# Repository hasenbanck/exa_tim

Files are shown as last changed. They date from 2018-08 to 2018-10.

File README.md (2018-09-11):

# EXA_tim

EXA_tim is a wristwatch that uses GNSS for time synchronization.

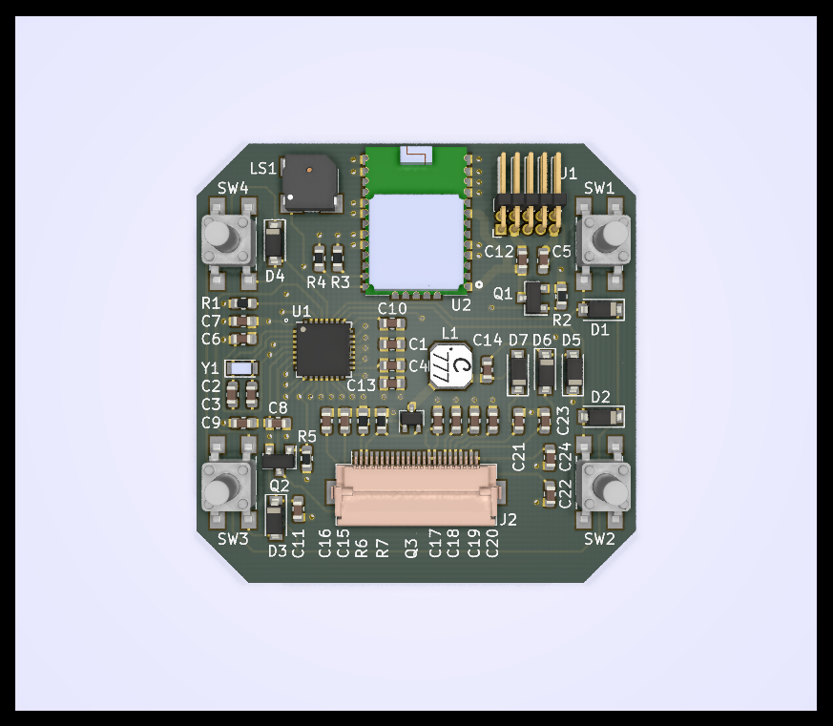
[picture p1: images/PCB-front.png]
EXA_tim PCB front

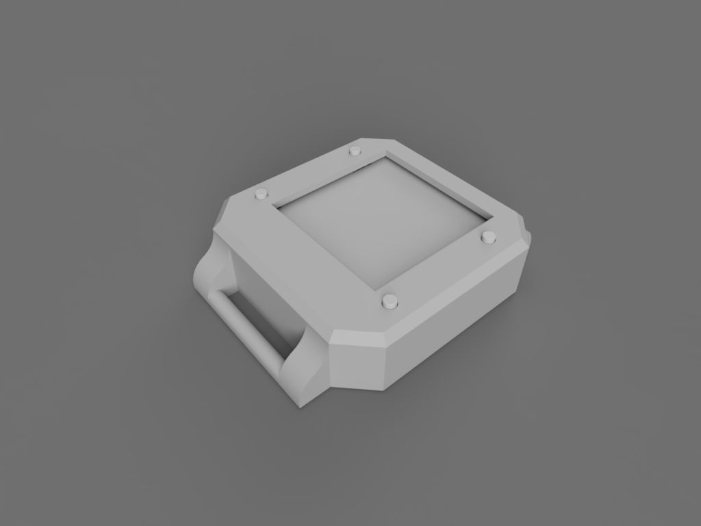
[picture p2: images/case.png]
EXA_tim case


# Features

- 32bit STM32L0 MCU
- GNSS time synchronization (UTC)
- 1.54 inch e-paper display
- 4 buttons
- CR2032 battery

Currently we are aiming for 2-3 months of operation with one battery.

# Case

The case is designed in Fusion 360 and can be viewed here:
https://a360.co/2LLzCpt

A current snapshot is included in the source repository.

The case is designed to be 3D printable and uses a NATO strap.

If you want to 3D print them, you need to either use Fusion 360 or
FreeCAD to export the three components as STL files.

I printed them in PLA and PETG with good results. Low warp material
hightly recommended, since dimensional accuracy is key.

I designed the parts for a printer that can handle 0.1 mm clearance.
If you need looser clearance, please change the Fusion 360 user
variable "Clearance" for your needed value.

# Firmware

The firmware uses the STM32 HAL. It can be build by either using cmake
with the ARM GCC toolchain or by using Atollic TrueStudio.

For the CMAKE build, you need to provide the ARM GCC toolchain in the
PATH of your system. You can choose any CMAKE target that you like
to use. I personaly use ninja.

```bash
cd firmware
cmake -DCMAKE_TOOLCHAIN_FILE=arm-gcc-toolchain.cmake -G Ninja .
ninja
```

You can change add a ```-DCMAKE_BUILD_TYPE=Debug``` to the CMAKE
command to produce a debug build.

# Flashing

To programm the watch we are using the 10 pin 1.27mm (0.05") Cortex Debug
header. You need a programmer that can programm an ARM using the SWD
protocol.

A ST-Link V2 (and it's clones), a JLink (mini) or a blackmagic programmer
should work fine.

We included a OpenOCD file as an example how to programm the firmware.

You can also use any available flashing software available. For example:
 - OpenOCD
 - STM32CubeProgrammer
 - STM32 ST-Link utility
 - Segger J-Link JFlash (lite)

# License

The hardware components (case and PCB) are licensed under the CERN Open
Hardware Licence v1.2

The software components (firmware) are licensed under GPLv3.

The pcb/packages3d files are excluded from these license.

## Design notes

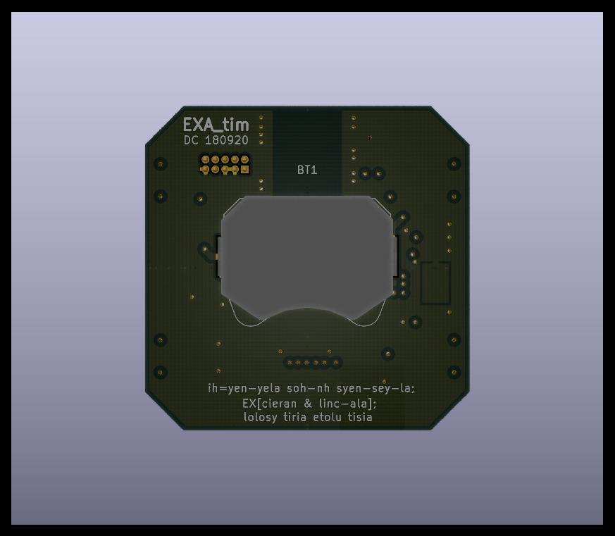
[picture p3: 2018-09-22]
images/PCB-back.png

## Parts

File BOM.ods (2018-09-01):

Item | Reference(s) | Value | Mouser | Qty | Notice | Footprint | Datasheet
1 | BT1 | 3034TR | 534-3034TR | 1 |  | exa_tim:BatteryHolder_Keystone_3034_1x20mm | http://www.keyelco.com/product-pdf.cfm?p=798
2 | C1, C6, C12, C13 | 4.7uF | 963-JMK107C6475MA-T | 4 | 6V | Capacitor_SMD:C_0603_1608Metric | ~
3 | C2, C3 | 20pF | 603-CC0603JR7BN200 | 2 | 6V | Capacitor_SMD:C_0603_1608Metric | ~
4 | C4, C5, C7, C9, C10, C11, C14, C17 | 100nF | 810-C1608X8R1H104M0B | 8 | 50V | Capacitor_SMD:C_0603_1608Metric | ~
5 | C8, C15, C16, C18, C19, C20, C21, C22, C23, C24 | 1uF | 710-885012106022 | 10 | 25V | Capacitor_SMD:C_0603_1608Metric | ~
7 | D1, D2, D3, D4, D5, D6, D7 | MBR0530 | 512-MBR0530 | 7 | Alternative: S310FA | Diode_SMD:D_SOD-123 | https://www.fairchildsemi.com/datasheets/MB/MBR0530.pdf
8 | J1 | 20021112-00010T4LF | 649-200211120001T4LF | 1 |  | Connector_PinHeader_1.27mm:PinHeader_2x05_P1.27mm_Horizontal | http://infocenter.arm.com/help/topic/com.arm.doc.faqs/attached/13634/cortex_debug_connectors.pdf
9 | J2 | FH12-24S-0.5SH(55) | 798-FH12-24S-0.5SH55 | 1 |  | exa_tim:Hirose_FH12-24S-0.5SH_1x24-1MP_P0.50mm_Horizontal | https://www.mouser.de/datasheet/2/185/FH12_catalog-939276.pdf
10 | L1 | LPS4018-683MRB | 994-LPS4018-683MRB | 1 |  | exa_tim:L_Coilcraft_LPS4018 | https://www.mouser.de/datasheet/2/597/lps4018-270702.pdf
11 | LS1 | CSS-0575A-SMT | 490-CSS-0575A-SMT-TR | 1 |  | exa_tim:CUI_CSS-0575A-SMT | ~
12 | Q1 | SI2333DS-T1-E3 | 781-SI2333DS-T1-E3 | 1 |  | Package_TO_SOT_SMD:SOT-23 | https://www.vishay.com/docs/72023/72023.pdf
13 | Q2 | DMN3067LW-7 | 621-DMN3067LW7 | 1 |  | Package_TO_SOT_SMD:SOT-323_SC-70 | https://www.mouser.de/datasheet/2/115/DMN3067LW-335715.pdf
14 | R1, R3, R6 | 1M | 603-RC0603JR-131ML | 3 |  | Resistor_SMD:R_0603_1608Metric | ~
16 | R2, R4, R5 | 220 | 603-RC0603JR-13220RL | 3 |  | Resistor_SMD:R_0603_1608Metric | ~
17 | R7 | 3 | 667-ERJ-PA3J3R0V | 1 |  | Resistor_SMD:R_0603_1608Metric | ~
18 | SW1, SW2, SW3, SW4 | TL3305CF260QG | 612-TL3305CF260QG | 4 |  | exa_tim:TL3305 | https://www.mouser.de/datasheet/2/140/TL3305-844809.pdf
19 | U1 | STM32L071KZU6 | 511-STM32L071KZU6 | 1 |  | exa_tim:QFN-32-1EP_5x5mm_P0.5mm_EP3.45x3.45mm | http://www.st.com/st-web-ui/static/active/en/resource/technical/document/datasheet/DM00141136.pdf
20 | U2 | CAM-M8C-0 |  | 1 | https://www.u-blox.com/de/product/cam-m8-series | exa_tim:LCC100P960X1400X210-31N
21 | Y1 | 9HT11-32.768KDZF-T | 717-9HT11-32.7KDZF-T | 1 |  | exa_tim:Crystal_SMD_TXC_9HT11-2Pin_2.0x1.2mm_HandSoldering | http://www.txccrystal.com/images/pdf/9ht11.pdf

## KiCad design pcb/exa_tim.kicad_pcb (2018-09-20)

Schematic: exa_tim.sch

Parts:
BT1: 3034TR; BatteryHolder_Keystone_3034_1x20mm
C1, C6, C12, C13: 4.7uF; C_0603_1608Metric
C2, C3: 4pF; C_0603_1608Metric
C4, C5, C7, C9, C10, C11, C14, C17: 100nF; C_0603_1608Metric
C8, C15, C16, C18, C19, C20, C21, C22, C23, C24: 1uF; C_0603_1608Metric
D1, D2, D3, D4, D5, D6, D7: MBR0530; D_SOD-123
J1: 20021112-00010T4LF; PinHeader_2x05_P1.27mm_Horizontal
J2: FH12-24S-0.5SH(55); Hirose_FH12-24S-0.5SH_1x24-1MP_P0.50mm_Horizontal
L1: LPS4018-683MRB; L_Coilcraft_LPS4018
LS1: CUI_CSS-0575A-SMT
Q1, Q2: SI2333DS-T1-E3; SOT-23
Q3: DMN3067LW-7; SOT-323_SC-70
R1, R2, R5, R6: 1M; R_0603_1608Metric
R3, R4: 220; R_0603_1608Metric
R7: 3; R_0603_1608Metric
SW1, SW2, SW3, SW4: TL3305CF260QG; TL3305
U1: STM32L071KZUx; QFN-32-1EP_5x5mm_P0.5mm_EP3.45x3.45mm
U2: CAM-M8C-0; LCC100P960X1400X210-31N
Y1: ST2012SB32768B0HPWBB; Crystal_SMD_TXC_9HT11-2Pin_2.0x1.2mm_HandSoldering

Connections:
3V: BT1.1, C1.2, C4.2, C6.2, C7.2, C8.2, C9.2, C10.2, C13.1, J1.1, L1.1, Q1.2, Q2.2, R2.2, R5.2, SW1.1, SW2.1, SW3.1, SW4.1, U1.5 (VDDA), U1.17 (VDD), U1.24 (VDDIO2), U1.32 (VDD)
/ALARM: LS1.1, U1.7 (PA1)
/BTN1: D1.2, SW1.2, U1.27 (PB5)
/BTN2: D2.2, SW2.2, U1.26 (PB4)
/BTN3: D3.2, SW3.2, U1.29 (PB7)
/BTN4: D4.2, SW4.2, U1.28 (PB6)
/BUSY: J2.9, U1.12 (PA6)
/CS: J2.12, U1.18 (PA8)
/DC: J2.11, U1.14 (PB0)
/DISP_EN: Q2.1, R5.1, U1.10 (PA4)
/GDR: J2.2, Q3.1, R6.1
/GNSS_EN: Q1.1, R2.1, U1.22 (PA12)
/MOSI: J2.14, U1.13 (PA7)
/NRST: C5.2, J1.10, U1.3 (NRST)
/PREVGH: C21.1, D7.1, J2.21
/PREVGL: C23.1, D6.2, J2.23
/RESE: J2.3, Q3.2, R7.1
/RESET: J2.10, U1.15 (PB1)
/RF: U2.16, U2.17
/RX: R3.2, U1.9 (PA3)
/RX_GNSS: R4.1, U2.26
/SCK: J2.13, U1.11 (PA5)
/SWCLK: J1.4, U1.25 (PA14)
/SWDIO: J1.2, U1.23 (PA13)
/TX: R4.2, U1.8 (PA2)
/TX_GNSS: R3.1, U2.25
/VDD_DISP: C17.1, J2.15, J2.16, Q2.3
/VDD_GNSS: C12.2, Q1.3, U2.1, U2.8, U2.9
/WKUP1: C11.1, D1.1, D2.1, D3.1, D4.1, U1.6 (PA0)
unnamed: C2.1, U1.1 (PC14), Y1.1
unnamed: C3.1, U1.2 (PC15), Y1.2
unnamed: C14.1, D5.2, D6.1
unnamed: C14.2, D7.2, L1.2, Q3.3
unnamed: C15.1, J2.4
unnamed: C16.2, J2.5
unnamed: C18.1, J2.18
unnamed: C19.1, J2.19
unnamed: C20.1, J2.20
unnamed: C22.1, J2.22
unnamed: C24.1, J2.24
unnamed: R1.2, U1.30 (BOOT0)

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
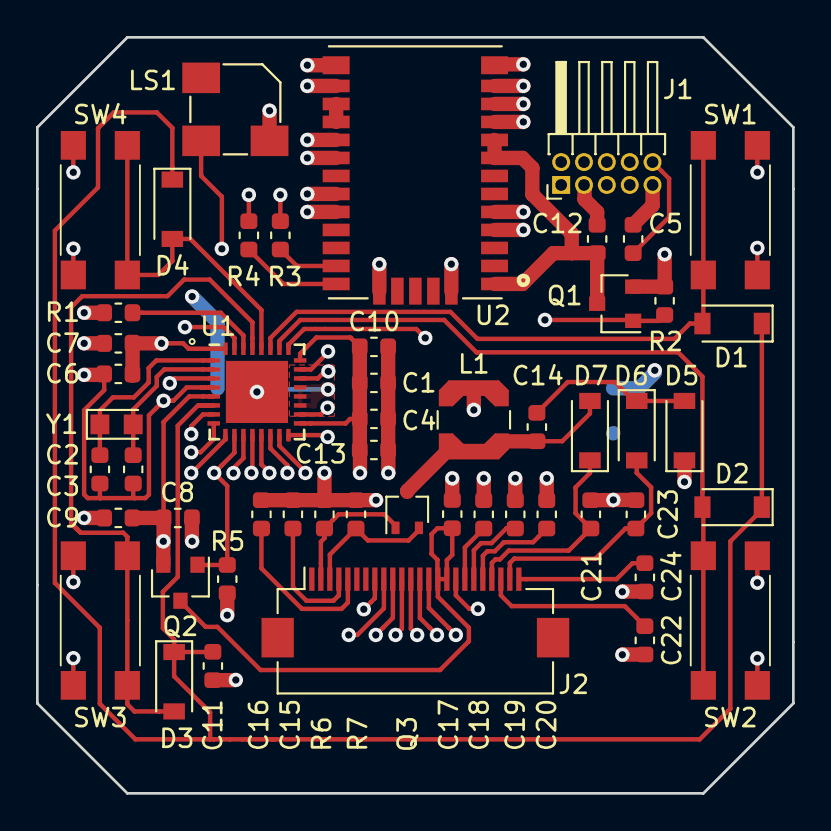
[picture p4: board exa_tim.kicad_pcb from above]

Board: 4 copper layers, 42.0 x 42.0 mm, 53 parts (1 on the bottom side), 42 nets.

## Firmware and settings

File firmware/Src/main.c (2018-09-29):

#include "main.h"
#include "alarm.h"
#include "button.h"
#include "clock.h"
#include "config.h"
#include "display.h"
#include "logic.h"
#include "power.h"
#include "stm32l0xx_hal.h"

#include <stdbool.h>

const uint32_t BUTTON_TIMEOUT = 10;
const uint32_t ALARM_TIMEOUT = 30000;

LPTIM_HandleTypeDef hlptim1;
UART_HandleTypeDef hlpuart1;
RTC_HandleTypeDef hrtc;
SPI_HandleTypeDef hspi1;
TIM_HandleTypeDef htim2;

bool checkAlarmTimer(applicationState_t *state) {
  config_t config = loadConfig();
  if (config.alarmActivated && (state->currentHours == config.alarmHours) &&
      (state->currentMinutes == config.alarmMinutes) &&
      (state->lastAlarmDay != state->currentDay)) {
    state->lastAlarmDay = state->currentDay;
    return true;
  }
  return false;
}

bool checkGNSSTimer(applicationState_t *state) {
  config_t config = loadConfig();
  // Sync is every night at 01:27
  if (config.syncActivated && (state->currentHours == 1) &&
      (state->currentMinutes == 27) &&
      (state->lastGNSSDay != state->currentDay)) {
    state->lastGNSSDay = state->currentDay;
    return true;
  }
  return false;
}

int main(void) {
  /* Reset of all peripherals, Initializes
   * the Flash interface and the Systick
   */
  HAL_Init();

  /* Initializes normal operation mode */
  initNormalMode();

  /* Get current application state */
  applicationState_t state = loadState();

  /* Reset button history */
  inputEvent_t in;
  btnBitField field;
  uint32_t timeoutCounter = 0;
  uint32_t timeout = BUTTON_TIMEOUT;

  /* Look if we have reache a new time code */
  in = needTimeUpdate(&state);
  while (1) {
    // Test for events
    field = getPressedButtonEvent();
    if (checkAlarmTimer(&state)) {
      in = inputEvent_Alarm_Timer;
    } else if (checkGNSSTimer(&state)) {
      in = inputEvent_GNSS_Timer;
    } else if (field & BTN1_BIT) {
      in = inputEvent_Button_1;
    } else if (field & BTN2_BIT) {
      in = inputEvent_Button_2;
    } else if (field & BTN3_BIT) {
      in = inputEvent_Button_3;
    } else if (field & BTN4_BIT) {
      in = inputEvent_Button_4;
    }

    outputEvent_t out = handleEvent(&state, in);

    if (out == outputEvent_StartAlarm) {
      state.alarmActive = true;
      startAlarmTone();
      out = outputEvent_Draw;
    }

    if (out == outputEvent_GNSS_Sync) {
      // TODO: Implement GNSS sync
    }

    if (out == outputEvent_Draw) {
      initDisplay(&state);
      drawDisplay(&state);
    }

    if ((timeoutCounter >= timeout) || out == outputEvent_Draw) {
      if (out == outputEvent_Draw) {
        // clang-format off
        while (isDisplayBusy());
        // clang-format on
        powerOffDisplay();
      }

      if (!state.alarmActive) {
        saveState(&state);
        switchStandbyMode();
      }
    }

    if (state.alarmActive) {
      timeout = ALARM_TIMEOUT;

      if (timeoutCounter == timeout || out == outputEvent_StopAlarm) {
        state.alarmActive = false;
        stopAlarmTone();
      }

      if ((timeoutCounter % 250) == 0) {
        toggleAlarmTone();
      }

      switchSleepMode();
    } else
      switchStopMode();
    in = inputEvent_None;
    timeoutCounter++;
  }
}

/**
 * @brief  This function is executed in case of error occurrence.
 * @param  file: The file name as string.
 * @param  line: The line in file as a number.
 * @retval None
 */
void _Error_Handler(char *file, int line) {
  UNUSED(file);
  UNUSED(line);
  // clang-format off
  while (1);
  // clang-format on
}

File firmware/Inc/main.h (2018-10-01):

#pragma once

#define VERSION_MAJOR "1"
#define VERSION_MINOR "0"
#define VERSION_PATCH "0"
#define PRINT_VERSION VERSION_MAJOR "." VERSION_MINOR "." VERSION_PATCH

#define ALARM_Pin GPIO_PIN_1
#define ALARM_GPIO_Port GPIOA
#define GNSS_EN_Pin GPIO_PIN_12
#define GNSS_EN_GPIO_Port GPIOA
#define DISP_EN_Pin GPIO_PIN_4
#define DISP_EN_GPIO_Port GPIOA
#define BUSY_Pin GPIO_PIN_6
#define BUSY_GPIO_Port GPIOA
#define DC_Pin GPIO_PIN_0
#define DC_GPIO_Port GPIOB
#define RESET_Pin GPIO_PIN_1
#define RESET_GPIO_Port GPIOB
#define SCK_Pin GPIO_PIN_5
#define SCK_GPIO_Port GPIOA
#define MOSI_Pin GPIO_PIN_7
#define MOSI_GPIO_Port GPIOA
#define CS_Pin GPIO_PIN_8
#define CS_GPIO_Port GPIOA
#define BTN1_Pin GPIO_PIN_5
#define BTN1_GPIO_Port GPIOB
#define BTN2_Pin GPIO_PIN_4
#define BTN2_GPIO_Port GPIOB
#define BTN3_Pin GPIO_PIN_7
#define BTN3_GPIO_Port GPIOB
#define BTN4_Pin GPIO_PIN_6
#define BTN4_GPIO_Port GPIOB

void _Error_Handler(char *, int);
#define Error_Handler() _Error_Handler(__FILE__, __LINE__)

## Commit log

2018-08-20 Initial commit of exa_tim
    A PCB for a watch that has following features:
    - 32bit STM32L0 MCU
    - GNSS for getting the current UTC time
    - e-paper as a display
    PCB size is 42x42mm
    [exa_tim.kicad_pcb, exa_tim.sch]
2018-08-20 Add name, version and fab instructions to PCB
    [exa_tim.kicad_pcb]
2018-08-20 General cleanup
    [exa_tim.kicad_pcb, exa_tim.sch]
2018-08-23 Rework GND plane, power distrubution and PU
    PU are now 1M ohm. GND is the only power plane.
    [exa_tim.kicad_pcb, exa_tim.sch]
2018-08-25 Added 3d models and moved some parts for fitting
    The 3d models are not licenced under the permissive licensce.
    They come from their manufacturer and some other free sources.
    [exa_tim.kicad_pcb, exa_tim.sch]
2018-08-25 Fix hirose connector 3d model placing
    [exa_tim.kicad_pcb]
2018-08-25 Changed epaper connection to bottom feeding
    Switched from FH12A to FH12, which is bottom feeding. This way the
    PCB doesn't need to be mounted with the top facing down.
    Also moved the battery now back to the original version. Hopefully
    the battery will fit properly.
    [exa_tim.kicad_pcb, exa_tim.sch]
2018-08-25 Rework PCP for more compact size
    I reworked the PCB layout to archive a more compact
    PCB layout / size. This should make the construction of
    the watch casing much more easier.
    Maybe we need to change the switches for a more fitting
    design (maybe SMD mounted switches).
    [exa_tim.kicad_pcb]
2018-08-27 Change battery to CR2032 for better height profile
    [exa_tim.kicad_pcb, exa_tim.sch]
2018-08-27 Use different buttons to get thinner design
    I used other buttons and relocated the buttons and the
    SWD connector to the bottom of the PCB to get a much
    thinner design. PCB will use a 1mm board.
    [exa_tim.kicad_pcb, exa_tim.sch]
2018-08-28 Cut PCB for buttons
    [exa_tim.kicad_pcb]
2018-08-30 Revert PCB cutout and change button layout
    Buttons are not top facing for easier assembly.
    First inner layer is now power lane.
    Removed useless LED, since we have no way to illuminate
    the epaper display.
    [exa_tim.kicad_pcb, exa_tim.sch]
2018-08-30 Chang Cortex Debug header to right angle TH
    [exa_tim.kicad_pcb, exa_tim.sch]
2018-08-31 Rework the project structure
    This way we can integrated firmware and case CAD files.
    [exa_tim.kicad_pcb, exa_tim.sch]
2018-08-31 Rework ground and power plane
    [exa_tim.kicad_pcb]
2018-08-31 Add snapshot of case
    Designed in Fusion 360, exported as IGES files (can be opened
    in FreeCad).
2018-08-31 Add message that only precious few will understand
    [exa_tim.kicad_pcb]
2018-08-31 Rework power plane and GND of STM32L0 chip
    [exa_tim.kicad_pcb]
2018-08-31 Change crystal caps from 21 to 20pF
    [exa_tim.kicad_pcb, exa_tim.sch]
2018-09-01 Add BOM for the PCB components
    [BOM.ods]
2018-09-01 Updated README.md and CASE CAD iges file
2018-09-03 Add firmeware template and renamed PCB folder to pcb
    You can build the firmware by either using make or Atollic True
    Studio.
    [exa_tim.kicad_pcb, exa_tim.sch]
2018-09-03 Add tiny_printf.c for smaller printf instructions
2018-09-03 Add first iteration of OpenOCD file
    This file hasn't been tested yet, since I don't have a working
    prototype for programming yet.
    I persoanly use a JTAG edu-mini, but any OpenOCD compatible
    SWD programmer should work.
2018-09-08 Remove LED pin from STM32 Cube configuration file
2018-09-08 Fixed LICENSE.txt
    Handled special case of middleware folder.
2018-09-09 Add simpler logging macro and extend Error_Handler
    [main.c, main.h]
2018-09-10 Add LPTIM1 for later usage for button debouncing
    Firing interrupts at 5ms. Should be stopped once watch
    goes into sleep mode.
2018-09-10 Add first try of a button debounce algorithm
    Also changed the interrupt priority of some interrupts.
2018-09-10 Fix the debounce algorithm
    C has the shift operation the other way around.
    I also added a little desciption to the algorithm.
    [button.c]
2018-09-11 Fix clang-format formatting
    VS Code falled back to the Visual Studio style.
    We now include a .clang-format with a LLVM style.
    [button.c, display.c, main.c]
2018-09-12 Add device definition for debugging in VS code
2018-09-14 Changed 2x06 header to 2x05 header
    I choosed the wrong header for the Cortex Debug header.
    This is the correct header. The old header is working fine
    but two holes are not used.
    [exa_tim.kicad_pcb, exa_tim.sch]
2018-09-15 Fix various small bugs and added test draw
    [button.c, display.c, main.c]
2018-09-15 Fix p-channel MOSFET and new routing
    Fixed the p-channel MOSFET drain/source problem (was reversed).
    New placement for the SWO header (2x05) for easier placement.
    Re-routed signals, so that ground and power lane are signal trace
    free.
    [exa_tim.kicad_pcb, exa_tim.sch]
2018-09-15 Reroute some GND vias
    [exa_tim.kicad_pcb]
2018-09-15 Move epaper display connector more upward
    This is needed, since the flexible connector hangs out too
    much and wouldn't fit into the case otherwise.
    [exa_tim.kicad_pcb]
2018-09-16 Add new font, add alarm, removed alarm series resistor
    The series resistor was not needed, since the alarm would be too
    tiny. I also added basic "beep" functionality.
    Also added a new font face size 96.
    [exa_tim.kicad_pcb, exa_tim.sch]
2018-09-16 Fixed button presse detection
    [button.c, display.c, main.c]
2018-09-16 Removed SPI DMA and optimized display handling
2018-09-16 Changed powerdown sequence of the display
    We will need to handle the display like we would handle it on
    power up. So just initalize it.
2018-09-16 Chang GNSS MOSFET to enh. N-Channel
    Changed the MOSFET so that we don't need a pullup,
    which might draw some precious power we don't want to
    waste.
    Also simplifies the BOM.
    [exa_tim.kicad_pcb, exa_tim.sch]
2018-09-17 First pass to re-arange parts to move connector
    [exa_tim.kicad_pcb, exa_tim.sch]
2018-09-17 Switched backt to high side p-channel MOSFET
    I don't want to risk communication errros of UART
    because of the otherwise not common ground levels.
    [exa_tim.kicad_pcb, exa_tim.sch]
2018-09-17 Second pass to reloacte many components up for connector placement
    [exa_tim.kicad_pcb]
2018-09-18 Redesigned LSE layout and re-routed some traces
    Also switched BTN3 and BTN4 pins for easier routing.
    [exa_tim.kicad_pcb, exa_tim.sch]
2018-09-18 Add SVD file and lowered LSE drive current
    I already use a 6pf crystall and still can't get it to run
    under RCC_LSEDRIVE_LOW or RCC_LSEDRIVE_MEDIUMLOW.
2018-09-19 Fixed display power down and button wakup
    TODO: RTC wakeup recognition (wakeup is not called)
    [display.c, main.c, power.c]
2018-09-19 Reworked wakup logic and time rendering
    When debugging the RTC gives odd values and I can't differentiate
    between normal standby wakeup and debug start.
    [button.c, display.c, main.c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]
2018-09-19 Fix RTC accuracy and running the watch under debug
    But running the watch without debug is now broken ...
    I can't seem to find a good way to distinguish between
    PWR ON and resuming from STANDBY.
    [power.c, time.c]
2018-09-20 Fix build using cmake/ninja
    [power.c]
2018-09-20 Switched LSE crystall for achieving LOW drive capability
    It seems my oscilloscope is interfering wit LSE
    operation when measuring and having the LOW drive
    capability on.
    But the LSE seeem to work fine, since the RTC and LPTIM
    seem to work fine under it.
    [exa_tim.kicad_pcb, exa_tim.sch]
2018-09-20 Add third MOSFET to shutdown E-Paper driver
    This will cut off the e-paper from any voltage source
    and should result in an even lower power usage.
    [exa_tim.kicad_pcb, exa_tim.sch]
2018-09-22 Fix some compilation errors under clang.
    [clock.c, display.c, main.c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]
2018-09-22 Update pictures of the PCB
2018-09-23 Added low power warning
    Using the internal PVD. Set around 2.7V.
2018-09-24 Rework build process, debugging logging and PVD
    [display.c, logic.c, main.c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]
2018-09-24 Removed RTT
    RTT doesn't work well in the current configuration.
    Maybe it's a memory leak in U8G2?
    [main.c, main.h, power.c]
2018-09-24 Code cleanup and trying to find 01:00 bug
    "01:00" bug stops the whole MCU after printing "01:00" to the
    watchface.
    But this only happens when starting at 00:59. Starting at 01:00
    works fine. 01:59 also works fine.
    [button.c, clock.c, display.c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]
2018-09-25 Fix "01:00" bug
    The TimerB was set to 01:00, which resulted in halting the MCU
    when going into standby when the TimerB was active.
    I reworked the timer logic and now the MCU doesn't freeze anymore.
    We don't need an interrupt, since our timer are only minute sensitive
    and we wake up the MCU every minute anyhow.
    [clock.c, display.c, logic.c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]
2018-09-25 Fix PVD bug
    We need to move the check to a later call time, since the
    PVD might not be ready.
    [display.c, logic.c, power.c]
2018-09-26 Update timezone configuration
    Alarms are not working as intended yet.
    [clock.c, config.c, display.c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]
2018-09-27 Reworked timer logic
    It's not RTC based anymore, which is fine.
    Somehow the button debounce needed a shorter timer interrupt.
    [clock.c, display.c, logic.c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]
2018-09-29 Implement timer based alarm
    The watch now uses sleep mode when running the timer for the alarm.
2018-10-01 Change enable pins for new board design
